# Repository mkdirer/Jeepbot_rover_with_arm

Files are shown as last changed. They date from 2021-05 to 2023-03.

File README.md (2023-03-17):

# Rover with arm
The Jeep-Bot project is an educational manipulator placed on a rover that uses stepper motors to drive its individual axes. The project can be divided into three parts: mechanical and electronic construction, software development, and application creation.

## Purpose and Scope
The main goal of the project is to create a cheap and functional design that can be controlled by a simple application. The project aims to achieve this goal by designing the mechanical parts of the Jeep-Bot, creating the robot's electronics to work with an external control system, writing software, creating an application for control, and conducting research.

## Technical Documentation
The technical documentation of the project describes the mechanical and electronic construction of the robot, as well as the software used to control the actuators and the application. The robot's control system only allows basic exercises related to identifying the geometric parameters of the manipulator.

<p align="center">
  
  
  
</p>

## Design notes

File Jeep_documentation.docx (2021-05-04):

[Wpisz nazwę firmy]

Jeep-Bot

ramię robota na łaziku

Łukasz Wajda

08.06.2018

[Wpisz tutaj streszczenie dokumentu. Streszczenie jest zazwyczaj krótkim podsumowaniem treści dokumentu. Wpisz tutaj streszczenie dokumentu. Streszczenie jest zazwyczaj krótkim podsumowaniem treści dokumentu.]

Rozdział 1

# Wstęp

Projekt „Jeep-Bot” jest to manipulator dydaktyczny umieszczony na łaziku. Do napędu jego poszczególnych osi zastosowano silniki krokowe. Projekt można podzielić na trzy części: konstrukcję mechaniczną i elektroniczną, oprogramowanie i aplikację. Konstrukcja mechaniczna i układ sterowania robota, pozwala jedynie na wykonywanie na nim podstawowych ćwiczeń związanych z identyfikacją parametrów geometrycznych manipulatora.

## 1.1 Cel i zakres pracy

Głównym celem stworzenia projektu jest wykonanie jak najtańszej, w miarę funkcjonalnej konstrukcji sterowanej prostą aplikacją. Stworzenie stanowiska z poruszającym się manipulatorem realizowane jest przez:

- wykonanie części mechanicznej Jeep-bota,
- zaprojektowanie i wykonanie elektroniki robota, pozwalającej współpracować z zewnętrznym układem sterowania,
- napisanie oprogramowania,
- stworzeni aplikacji do sterowania,
- przeprowadzenie badań.

W dokumentacji technicznej robota zamieszczono opis konstrukcji części mechanicznej i elektronicznej robota. Opisano też oprogramowanie służące do obsługi

układów wykonawczych wraz z aplikacją.

## 1.2 Czas przygotowania

Przygotowanie projektu trwało około 2 tygodni. Ten aktywnie spędzony czas można podzielić na kilka etapów. Pierwszy to pozyskanie niezbędnych części i złożenie projektu według własnego pomysłu. Drugi to pisanie jednocześnie programu pod Arduino UNO (mikrokontroler sterujący) i pod aplikację utworzoną w MIT App Inventor, wraz z testowaniem kilku linijek kodu. Trzeci etap to z kolei jego opisanie oraz przygotowanie niezbędnych schematów.

Rozdział 2

# Konstrukcja robota „Jeep-bot”

## 2.1 Konstrukcja mechaniczna

Projekt „Jeep-Bot” można podzielić na dwie podstawowe części: Ramię i Łazik. Rysunek ramienia powstał na podstawie projektu manipulatora MeArm Classic (https://shop.mime.co.uk/products/mearm-pocket-sized-robot-arm). Pozwoliłem sobie na kilka modyfikacji i udoskonaleń, ponieważ jego pierwowzór był przeznaczony na serwa modelarskie. Ja natomiast zaopatrzyłem się w tanie i dość wydajne silniki krokowe.

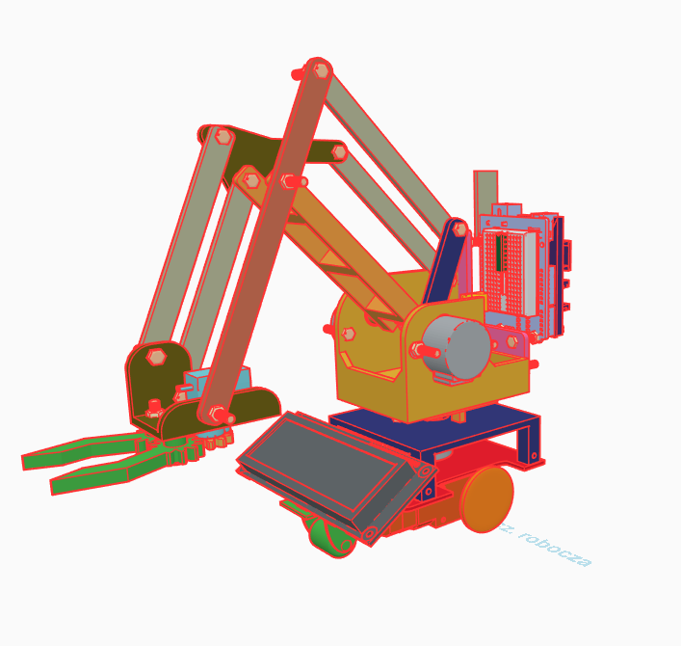
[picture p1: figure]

Do modyfikacji manipulatora posłużyłem się prostym i darmowym narzędziem online do tworzenia i edycji modeli 3D o nazwie TinkerCAD (jest własnością firmy Autodesk). Umieszczenie silników w skrzynce ma swoje pozytywne konsekwencje, a mianowicie stanowią on swego rodzaju przeciwwagę, co ma znaczenie ze względu na utrzymanie równowagi potrzebnej podczas ruchu głównego ramienia. Ramię zostało w całości wydrukowane na drukarce 3D. Jako materiał wybrałem ABS -tworzywo (https://pl.wikipedia.org/wiki/Tworzywa_sztuczne) otrzymywane w procesie polimeryzacji, które cechuje się dużą udarność (https://pl.wikipedia.org/wiki/Udarno%C5%9B%C4%87), twardością oraz odpornością na zarysowania. Jednak największym mankamentem tego materiału jest odklejanie się cienkich przedmiotów od stołu drukarki w czasie drukowania. Poniżej przedstawiono poszczególne kroki łączenia elementów.

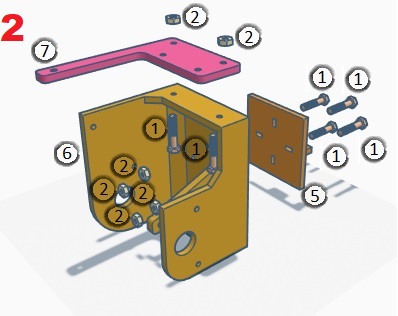
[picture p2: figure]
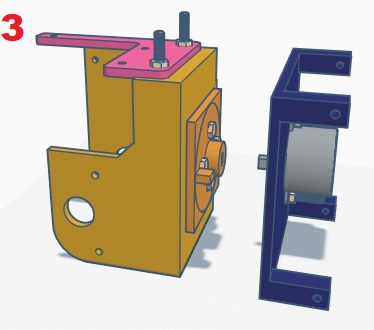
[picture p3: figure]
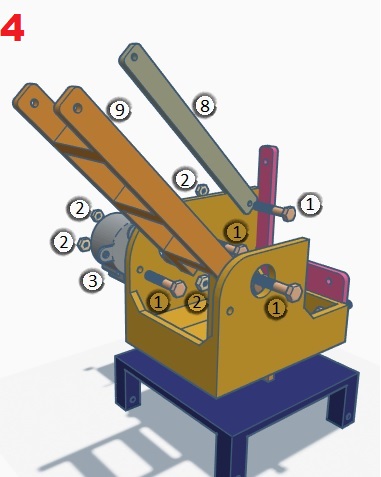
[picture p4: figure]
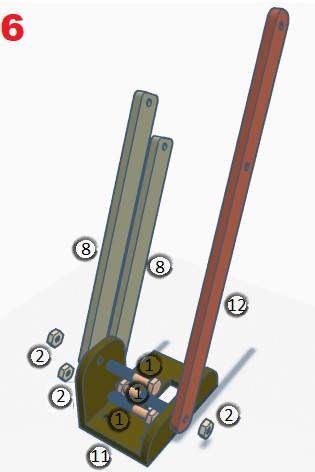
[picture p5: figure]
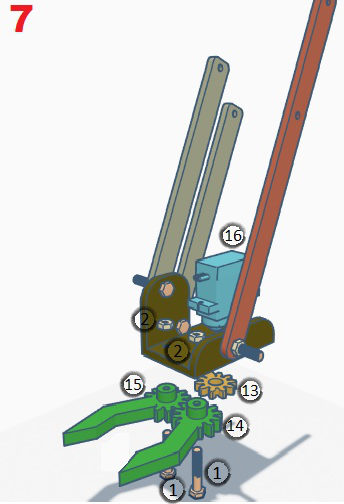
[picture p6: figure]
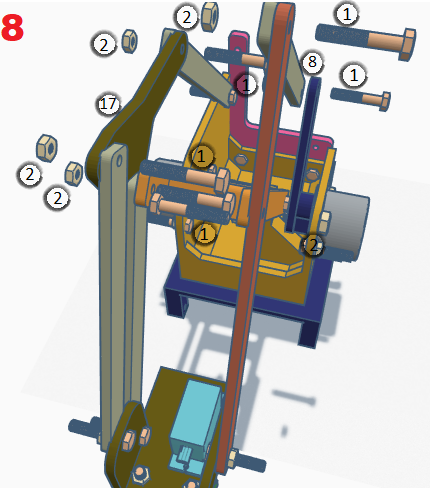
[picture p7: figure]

Płytki laminatu pod łazik zostały wycięta szlifierką i sklejone ciepłym klejem na których wspiera się manipulator. Poniżej zostało przedstawione umiejscowione dwóch silników i jednej rolki.

LISTA CZĘŚCI
Numer | Nazwa Części | Ilość
1 | M3 x 20mm Śruba | 29
2 | Nakrętka M3 | 32
3 | Silnik krokowy 28BYJ-48 | 3
4 | Podstawa manipulatora | 1
5 | Łącznik z silnikiem osi X | 1
6 | Skrzynia | 1
7 | Uchwyt na Arduino | 1
8 | Łącznik 100mm | 4
9 | Ramię silnika osi Z | 1
10 | Ramię silnika osi Y | 1
11 | Podstawa chwytaka | 1
12 | Łącznik 160mm | 1
13 | Koło zębate serwa | 1
14 | Chwytak lewy | 1
15 | Chwytak prawy | 1
16 | Micro Serwo 9g Tower Pro | 1
17 | Prawy górny łącznik | 1
18 | Płytka laminatu | 1
19 | Silnik DC z redukcją | 2
20 | Płytka obrotowa z kółkiem 22mm | 1
21 | Arduino Uno | 1
22 | CNC Shield | 1
23 | Sterownik A4988 (http://botland.com.pl/sterowniki-silnikow-krokowych/148-sterownik-silnika-krokowego-a4988-reprap-35v-2a-modul-pololu.html) | 3
24 | Płytka stykowa | 1
25 | Stabilizator LM7805 | 1
26 | Mostek H L293d | 1
27 | Moduł HC-06 | 1
28 | Wyświetlacz LCD 2x16 z konwerterem I2C HD 44780 | 1

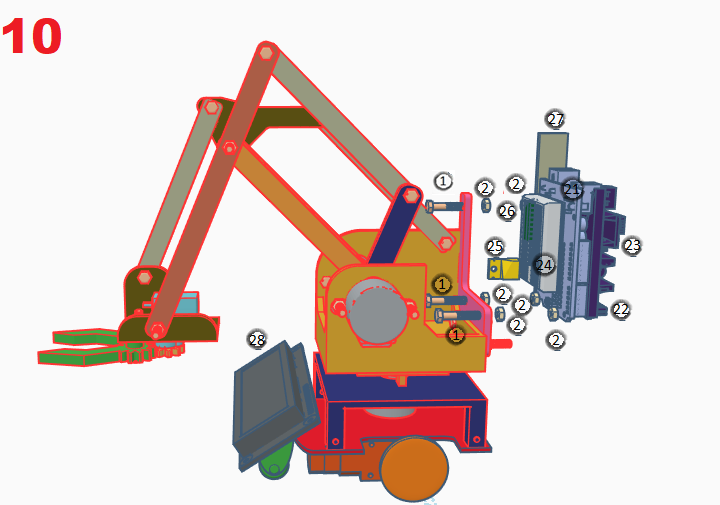
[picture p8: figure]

Pliki do druku zostały umieszczone w załączniku.

## 2.2 Konstrukcja elektroniczna

Sercem odpowiedzialnym za dokonywanie obliczeń, odbieranie danych i ich wysyłanie jest Arduino UNO, którego opis wyprowadzeń dla CNC shield i przykładowe umieszczenie przedstawiono poniżej.

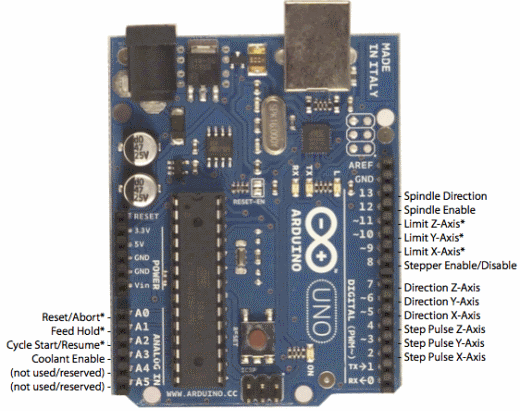
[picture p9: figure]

Specjalna nakładka CNC shield pozwala na wygodne umiejscowienie czterech sterowników silników A4988 (http://botland.com.pl/sterowniki-silnikow-krokowych/148-sterownik-silnika-krokowego-a4988-reprap-35v-2a-modul-pololu.html). W znaczący sposób ułatwia to korzystanie z silników krokowych odpowiedzialnych za poruszanie ramieniem w różnych płaszczyznach x, y i z .

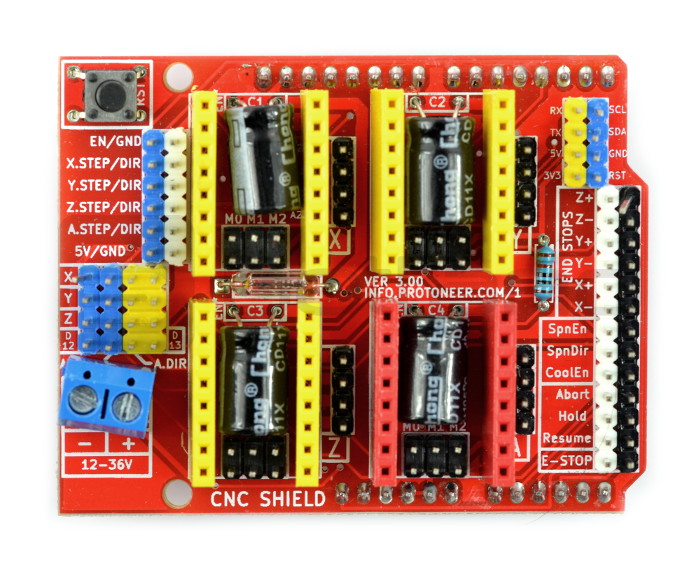
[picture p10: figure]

Silniki krokowe 28BYJ-48 są silnikami unipolarnymi, natomiast płytka jak i sterowniki są przeznaczone na silniki bipolarne. Ich przemiana była bardzo prosta i obejmowała ściągnięcie obudowy i zarysowanie, usunięcie jednej ścieżki łączącej środki uzwojeń silników.

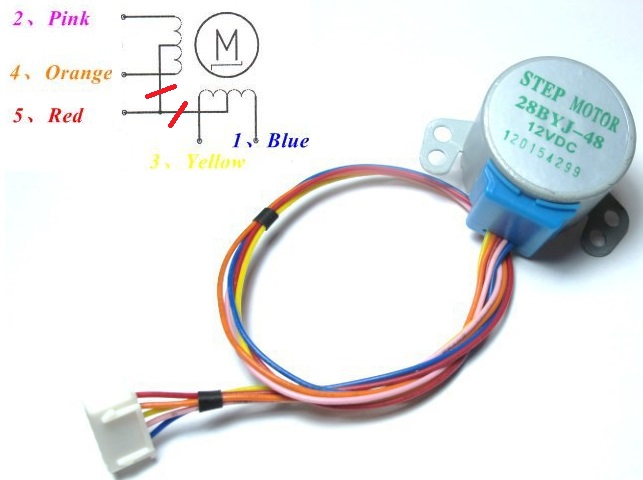
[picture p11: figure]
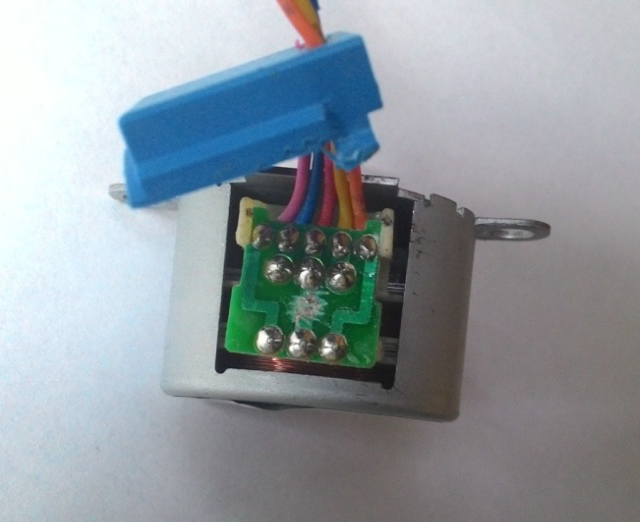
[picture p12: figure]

Do sterowania silnikami krokowymi za pomocą A4988 (http://botland.com.pl/sterowniki-silnikow-krokowych/148-sterownik-silnika-krokowego-a4988-reprap-35v-2a-modul-pololu.html) wymagane są dwa piny sterujące STEP i DIR. Jeden impuls podany na pin STEP powoduje jeden krok silnika w kierunku wybranym poprzez podanie odpowiedniego stanu logicznego na pin DIR.

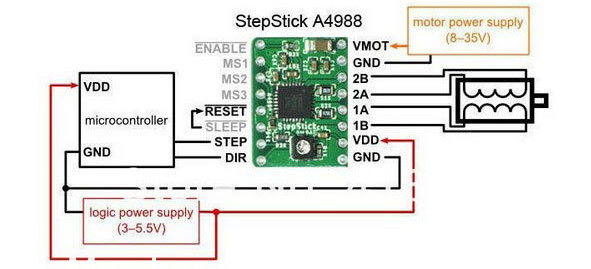
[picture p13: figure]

Mechanizmem który porusza chwytakiem w ramieniu jest serwo, wymaga tylko jednego pinu sterującego. Wyświetlacz LCD 2x16 został połączony z konwerterem I2C HD 44780. Dzięki temu połączenie między Arduino UNO, a wyświetlaczem zajmuje 4 piny (SCL, SDA, Vcc i GND).

Silniki DC łazika są odpowiednio połączone z L293d, mostkiem H (zgodnie z poniższym schematem). Całość jest zasilana napięciem 9V i 5V po stabilizatorze LM7805.

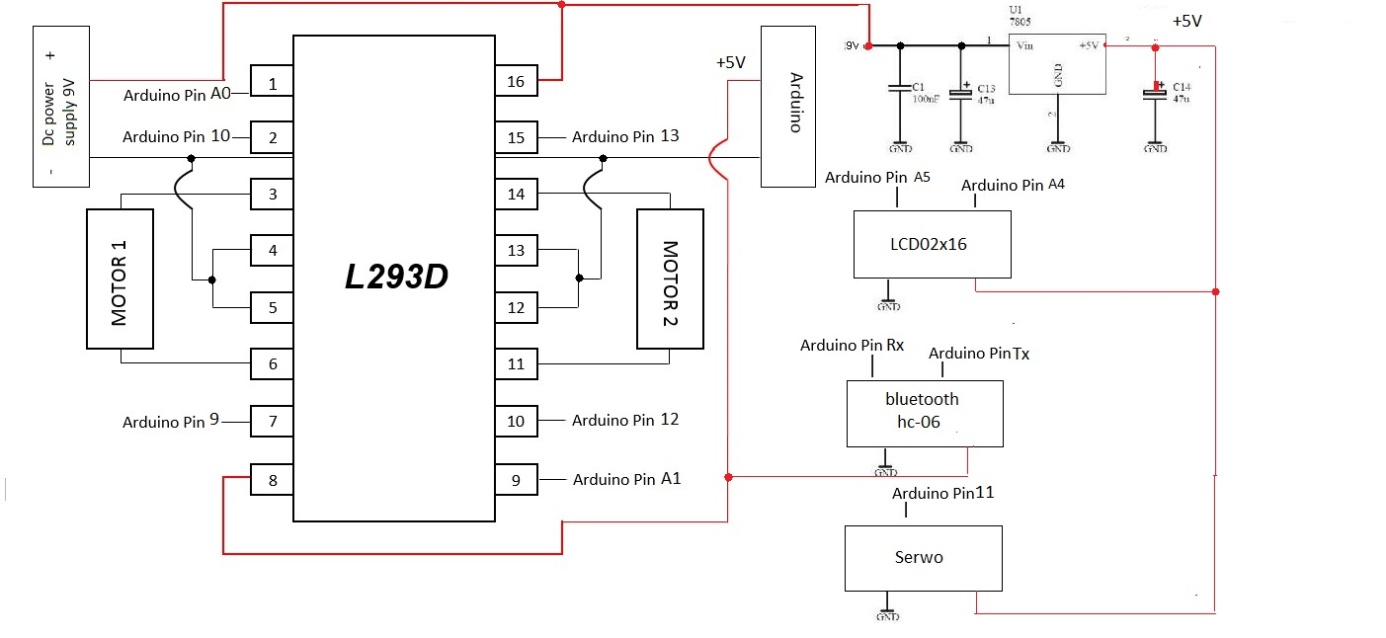
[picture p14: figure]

Najważniejszym elementem zapewniającym komunikację z aplikacją jest moduł Bluetooth HC-06. Na koniec wszystko powinno wyglądać tak

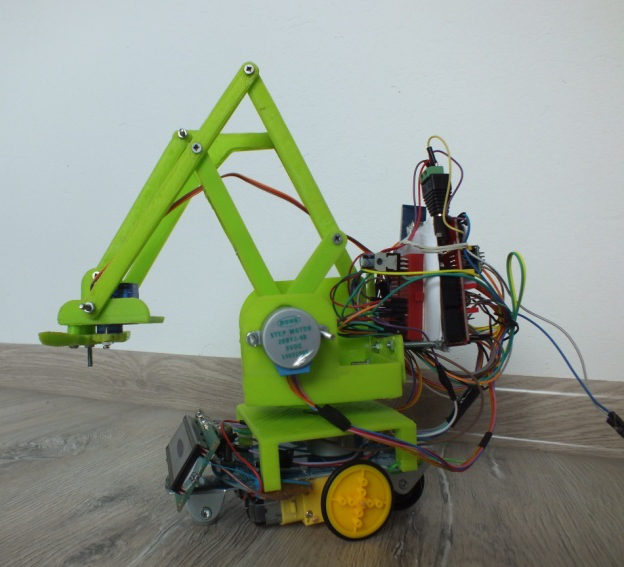
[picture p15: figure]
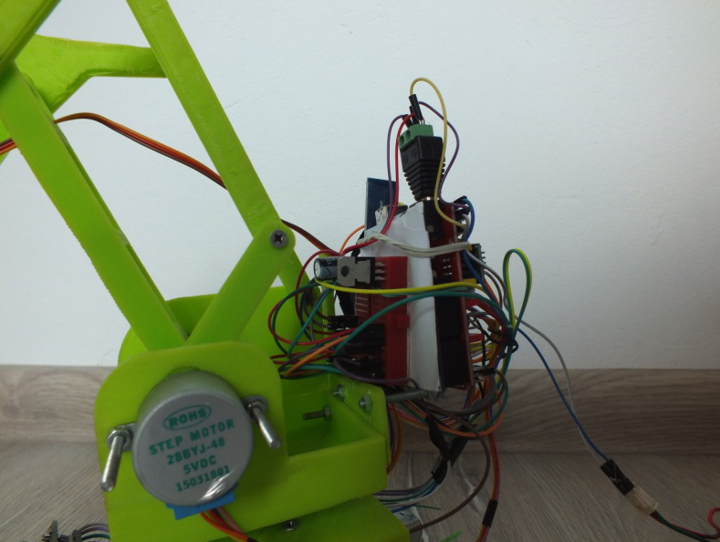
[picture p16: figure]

## 2.3 Aplikacja

Do stworzenia aplikacji użyłem programu wizualnego MIT App Inventor. App Inventor umożliwia tworzenie aplikacji dla telefonów z systemem Android za pomocą przeglądarki internetowej i podłączonego telefonu lub emulatora. Budujemy aplikacje poprzez współpracę z:

- App Inventor Designer, gdzie można wybrać składniki.

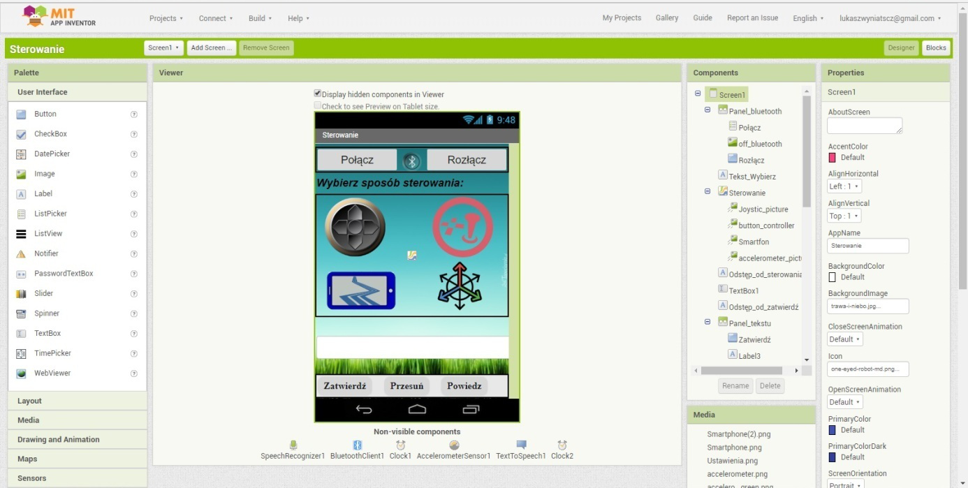
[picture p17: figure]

- App Inventor Blocks Editor, gdzie można zbudować bloki programu, które określają, w jaki sposób elementy powinny się zachowywać.

Każdemu składnikowi na ekranie tworzonej aplikacji odpowiadają konkretne bloki. Na samym początku okno startowe aplikacji wymaga od nas połączenia za pomocą Bluetooth. Wówczas aktywny jest tylko przycisk Połącz, dzięki procedurze przyciski_startu_po_rozłączeniu. Do inicjalizacji ekranu wchodzą również komendy takie jak : akcelerometr jest wyłączony i ustawiany joysticka w odpowiedniej pozycji, które szerzej zostaną opisane później.

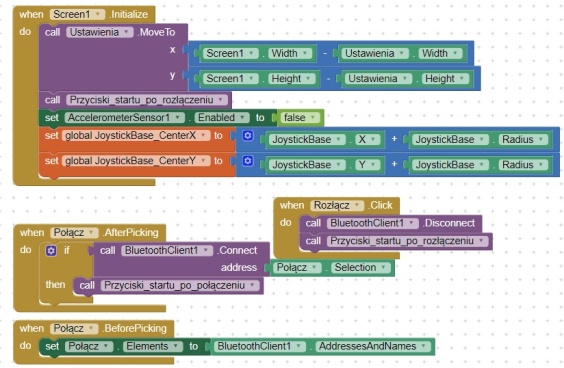
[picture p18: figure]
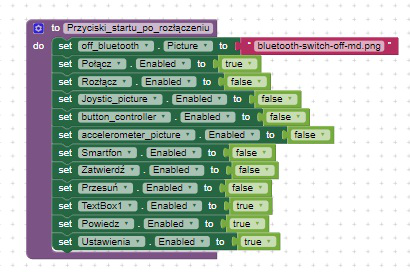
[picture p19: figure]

Po wybraniu znanego nam połączenia bluetooth mamy do wyboru kilka metod sterowania łazikiem, jak np.: przyciski, joystick, akcelerometr oraz przykładowy ruch i jedną metodę sterowania ramieniem.

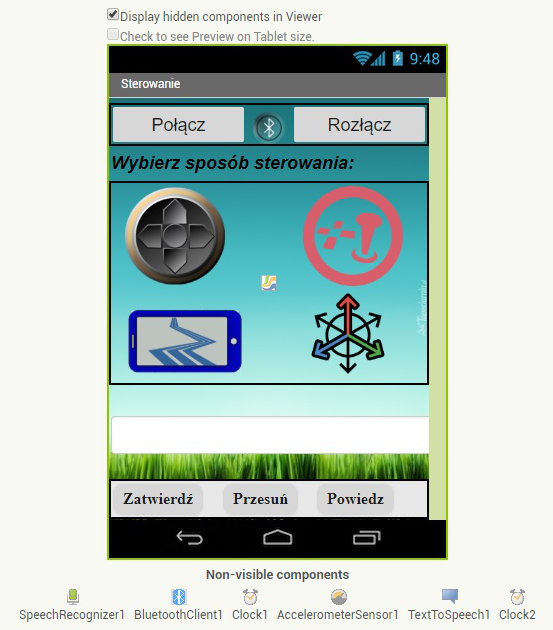
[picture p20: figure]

Dodatkowo możemy wysłać przykładowy tekst na wyświetlacz LCD, przesunąć go i sprawić, że nasz smartfon wypowie napisane słowo.

Po wybraniu dowolnego sposobu sterowania np. za pomocą przycisków, wykonywane są odpowiednie procedury odpowiedzialne za zakrywanie bądź odsłanianie konkretnych komponentów, tak aby uzyskać żądany ekran. Poniżej przedstawiono używane procedury.

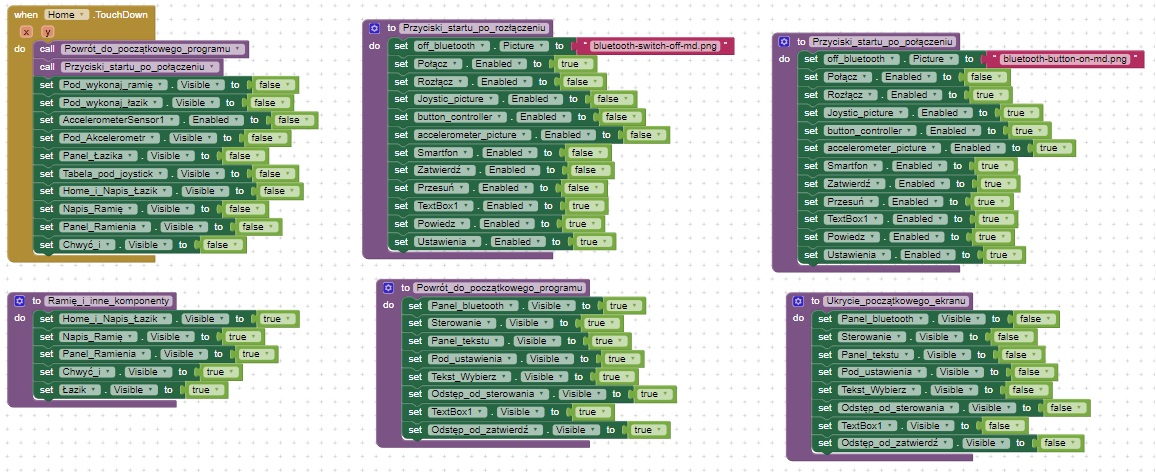
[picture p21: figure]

Co nastąpi kiedy naciśniemy wybrany przycisk.

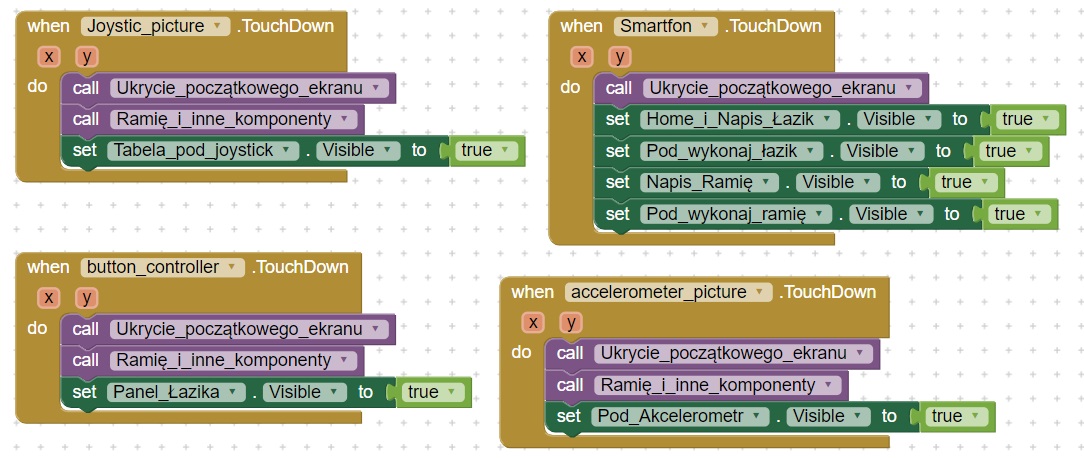
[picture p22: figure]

Uzyskane ekrany pod sterowanie:

- Przyciskami,
- Joystick,
- Akcelerometr,
- Przykładowy ruch.

W przypadku joysticka i akcelerometru musiałem utworzyć martwe pole, w którym nie jest wysyłana żadna komenda do łazika. Z przedstawionych bloków można się domyślić, że dla joysticka pole to jest kwadratem o boku 80 pikseli i po jego przekroczeniu wysyłana jest odpowiednia widomość. Ogólnie czerwony joystick może się poruszać po polu czarnego koła o średnicy 160 pikseli. Kiedy joystick jest nieużywany wraca do położenia środkowego martwego pola.

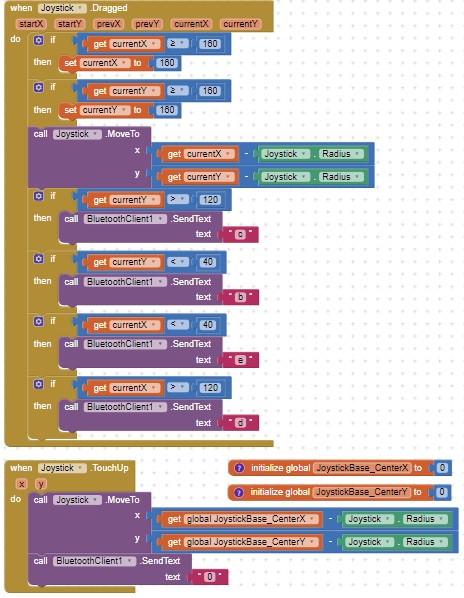
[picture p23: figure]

Dla akcelerometru sprawa ma się podobnie. W tym przypadku działamy tylko w dwóch płaszczyznach, osi X i Z. Do każdej osi jest przyporządkowany odpowiedni przedział, w którym jest wysyłana komenda „0” odpowiedzialna za bezruch. Dopiero jej przekroczenie skutkuje ruchem łazika.

Aplikacja jest tak zaprojektowana, aby w czasie naciśnięcia przycisku, bądź zadziałaniu akcelerometru lub joystick smartfon wysyłał poszczególne znaki np.: ‘1’, ‘2’, ‘A’, ’B’, ‘C’ itp.

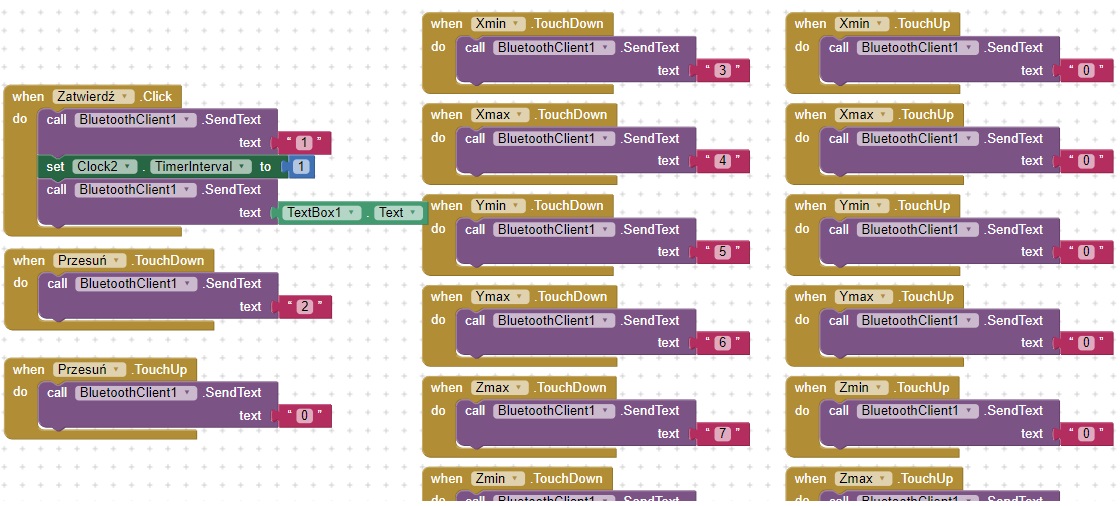
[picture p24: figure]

Kolejno moduł Bluetooth odbiera ciąg znaków, które za pomocą programu są przekształcane na poszczególne czynności. Program z opisem pod mikrokontroler wraz z aplikacją w załączniku.

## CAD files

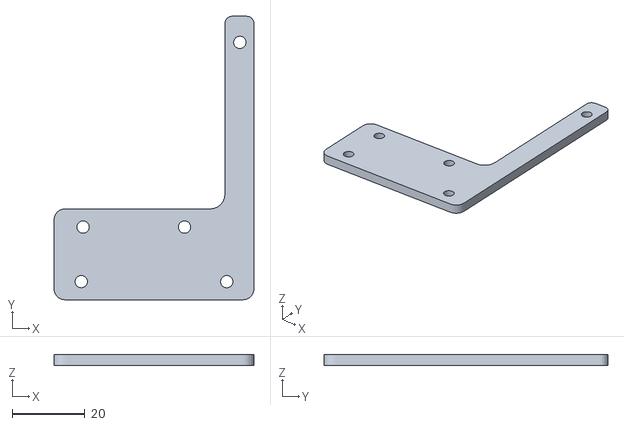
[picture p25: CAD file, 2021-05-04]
Part_to_3D_print/_uchwyt na Arduino.stl
55.0 x 78.0 x 3.00

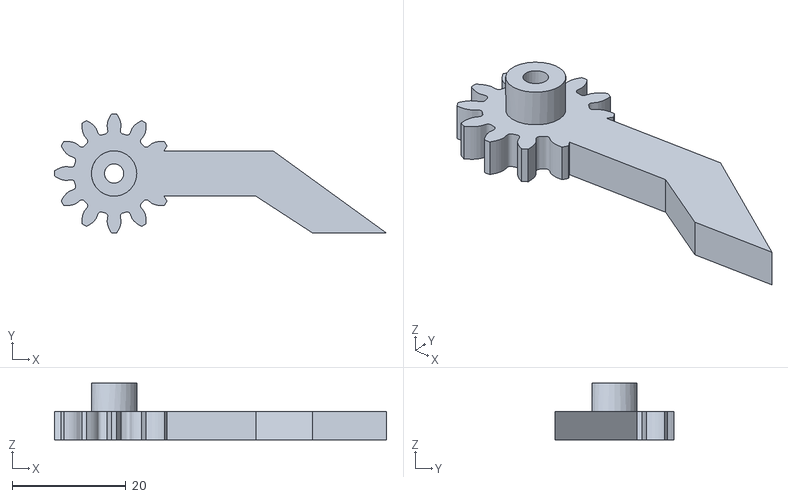
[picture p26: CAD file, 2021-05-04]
Part_to_3D_print/_chwytak lewy.stl
58.5 x 21.0 x 10.0

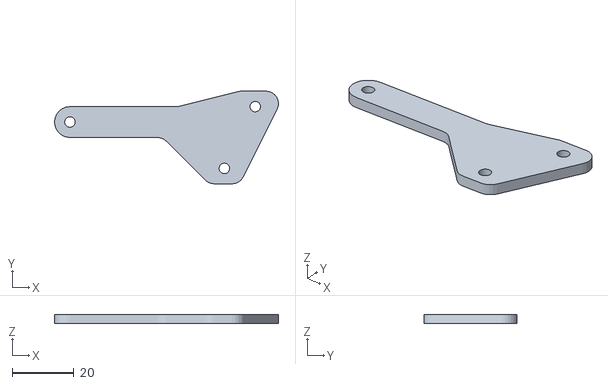
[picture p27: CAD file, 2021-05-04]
Part_to_3D_print/_prawy gorny łacznik.stl
72.5 x 30.0 x 3.00

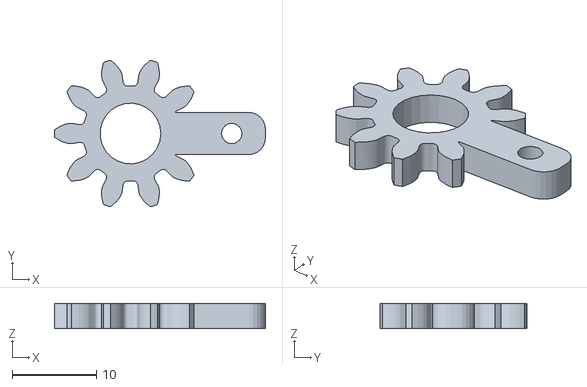
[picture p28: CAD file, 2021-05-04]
Part_to_3D_print/_koło zebate serwa.stl
25.0 x 17.4 x 3.00

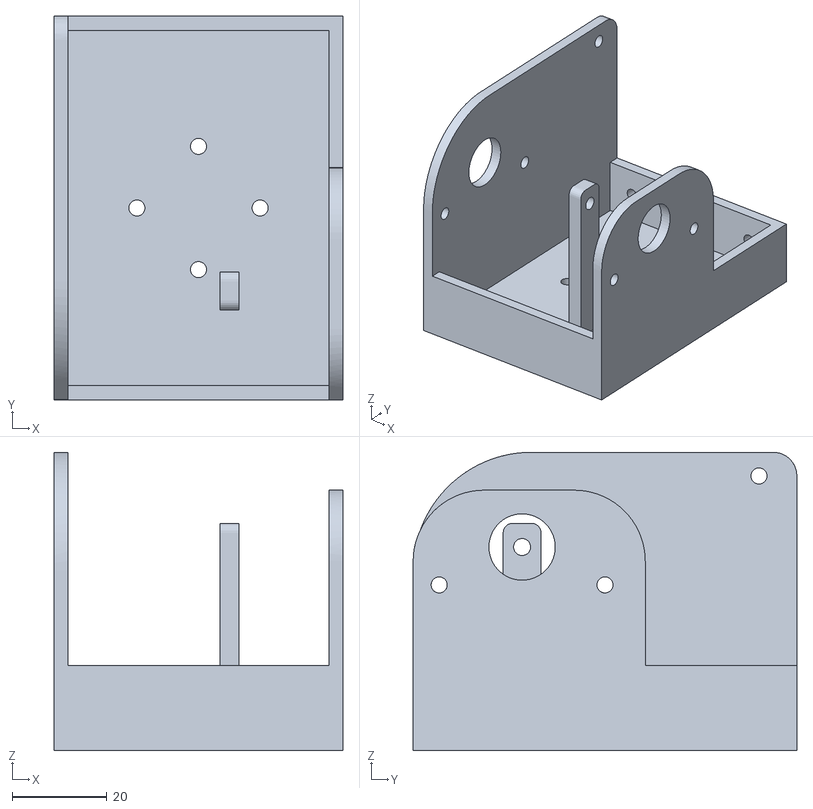
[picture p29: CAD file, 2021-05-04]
Part_to_3D_print/_skrzynia.stl
61.0 x 81.0 x 63.0

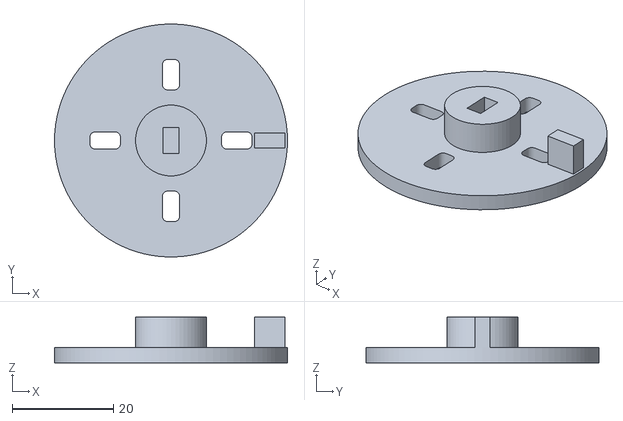
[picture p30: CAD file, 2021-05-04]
Part_to_3D_print/_łacznik z silnikiem osi X.stl
46.0 x 46.0 x 9.00

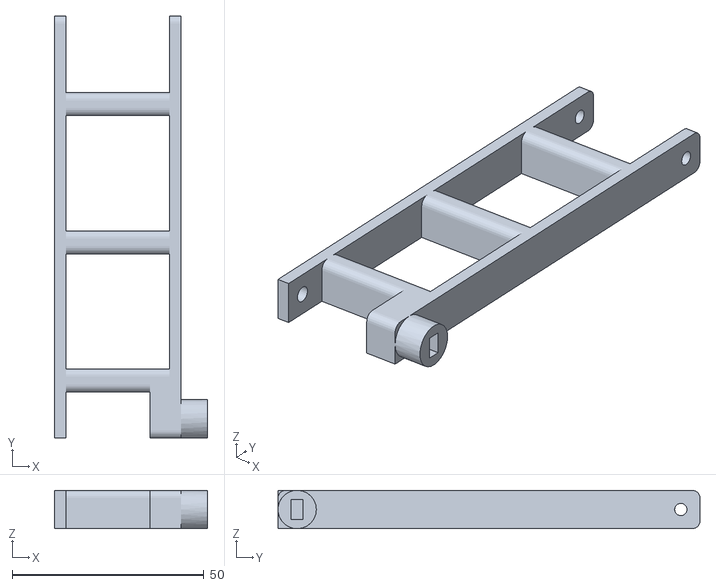
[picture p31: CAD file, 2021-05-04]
Part_to_3D_print/_ramie silnika osi Z.stl
40.0 x 110.0 x 10.0

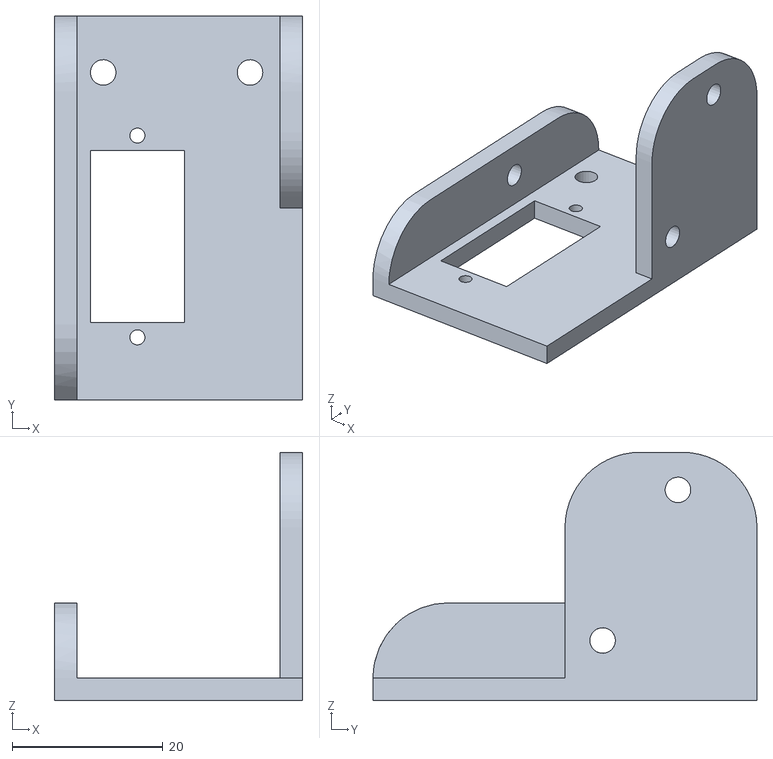
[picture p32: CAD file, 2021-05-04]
Part_to_3D_print/_podstawa chwytaka.stl
33.0 x 51.0 x 33.0

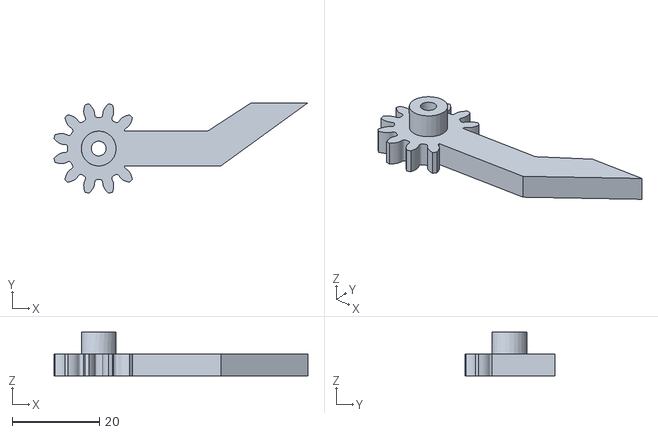
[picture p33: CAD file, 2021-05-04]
Part_to_3D_print/_chwytak prawy.stl
58.3 x 20.8 x 10.0

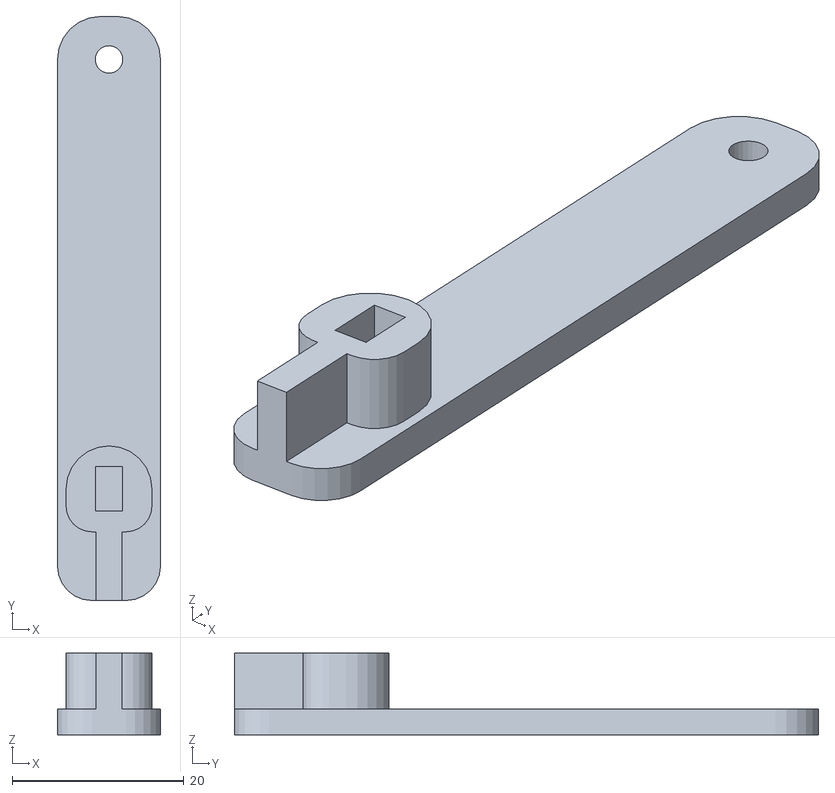
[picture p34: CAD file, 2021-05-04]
Part_to_3D_print/_ramie silnika osi Y.stl
12.0 x 68.0 x 9.50

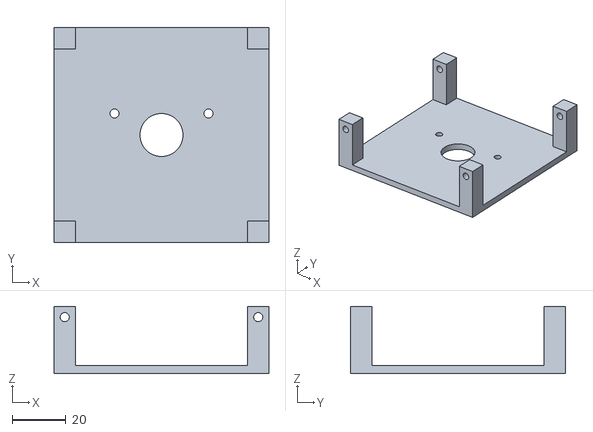
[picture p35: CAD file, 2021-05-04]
Part_to_3D_print/_podstawa manipulatora.stl
80.0 x 80.0 x 25.0

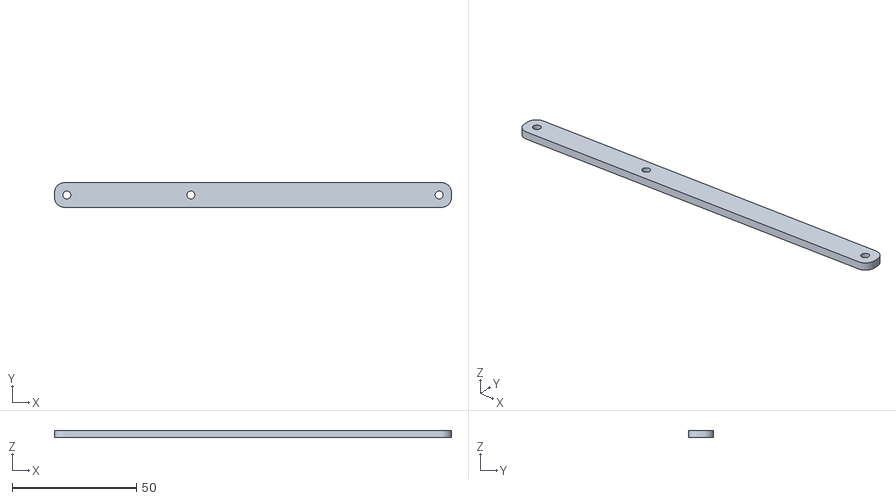
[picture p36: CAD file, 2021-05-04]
Part_to_3D_print/_łacznik 160mm.stl
160.0 x 10.0 x 3.00

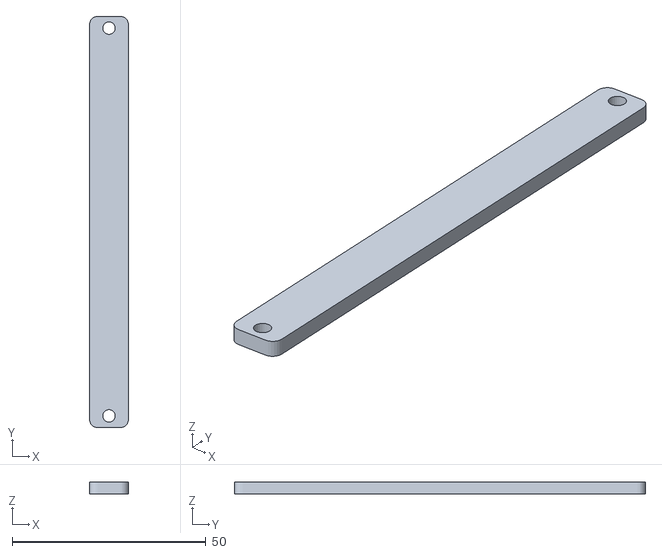
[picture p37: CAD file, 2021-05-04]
Part_to_3D_print/_łacznik 100mm.stl
10.0 x 106.0 x 3.00

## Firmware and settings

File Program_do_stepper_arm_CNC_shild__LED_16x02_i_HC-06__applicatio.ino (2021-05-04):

// Poniżej przedstawiono proste procedury sterowania silnikiem krokowym
# define EN 8 // Aktywacja silników krokowych, aktywny stan niski
# define X_DIR 5 // Sterowanie kierunkiem silnika krokowego w osi X.
# define Y_DIR 6 // Sterowanie kierunkiem silnika krokowego w osi Y.
# define Z_DIR 7 // Sterowanie kierunkiem silnika krokowego w osi Z.
# define X_STP 2 // Sterowanie krokowe, impulsowe x-osi
# define Y_STP 3 // Sterowanie krokowe, impulsowe y-osi
# define Z_STP 4 // Sterowanie krokowe, impulsowe x-osi

#include <Servo.h> //Biblioteka odpowiedzialna za serwa
#define serw 11 // Nazwanie pinu pod kontrolowanie serwa
Servo serwomechanizm;  //Tworzymy obiekt, dzięki któremu możemy odwołać się do serwa

char state;// Utworzenie zmiennej do odczytywania przesyłanych znaków

String message; // ciąg, który przechowuje wiadomość przychodzącą
#include <Wire.h> //
#include <LiquidCrystal_I2C.h> // biblioteki niezbędne do obsługi LCD
LiquidCrystal_I2C lcd(0x27, 16, 2);//Informacja o podłączeniu nowego wyświetlacza

#define pwmMotorA A0 // Sterowanie PWM silnikiem DC A (odpowiada z prędkość obrotów silnik A)
#define pwmMotorB A1 // Sterowanie PWM silnikiem DC B (odpowiada z prędkość obrotów silnik B)
#define ForwardA 9
#define BackA 10
#define ForwardB 12
#define BackB 13

// Funkcja: step. funkcja: do sterowania kierunkiem silnika krokowego, liczba kroków.
//Parametry: dir-sterowanie kierunkiem jazdy, dirPin-pin pod kierunek jazdy, 
//steps-liczba kroków, stepperPin- pin pod liczbę kroków

void step (boolean dir, byte dirPin, byte stepperPin, int steps)
{ digitalWrite (EN, LOW);
    digitalWrite (dirPin, dir);
    delay (30);
    for (int i = 0; i <steps; i++) 
    {
        digitalWrite (stepperPin, HIGH);
        delayMicroseconds (700);
        digitalWrite (stepperPin, LOW);
        delayMicroseconds (700);
    }
}
void ster (boolean dir, byte dirPin, byte stepperPin)
{for (int i = 0; i <15; i++)
  {digitalWrite (EN, LOW);
  digitalWrite (dirPin, dir);
    digitalWrite (stepperPin, HIGH);
        delayMicroseconds (700);
        digitalWrite (stepperPin, LOW);
        delayMicroseconds (700);}
    
}
//funkcja skręt w lewo
void Left(){
  //Ustawienie kierunku obrotów A
  digitalWrite(ForwardA, LOW); 
  digitalWrite(BackA, HIGH);
  //Ustawienie kierunku obrotów B
  digitalWrite(ForwardB, HIGH); 
  digitalWrite(BackB, LOW);
  //delay(1000);
}

//skręt w prawo
void Right(){
  //Ustawienie kierunku obrotów A
  digitalWrite(ForwardA, HIGH); 
  digitalWrite(BackA, LOW);
  //Ustawienie kierunku obrotów B
  digitalWrite(ForwardB, LOW); 
  digitalWrite(BackB, HIGH);
  
  //delay(1000);
}

//jazda prosto
void Forward(){
  //Ustawienie kierunku obrotów A
  digitalWrite(ForwardA, HIGH); 
  digitalWrite(BackA, LOW);
  
  //Ustawienie kierunku obrotów B
  digitalWrite(ForwardB, HIGH); 
  digitalWrite(BackB, LOW);
}

//cofanie
void Back(){
  //Ustawienie kierunku obrotów A
  digitalWrite(ForwardA, LOW); 
  digitalWrite(BackA, HIGH);
  
  //Ustawienie kierunku obrotów B
  digitalWrite(ForwardB, LOW); 
  digitalWrite(BackB, HIGH);
  
}
//zatrzymanie
void Stop(){
  //Ustawienie kierunku obrotów A
  digitalWrite(ForwardA, LOW); 
  digitalWrite(BackA, LOW);
  
  //Ustawienie kierunku obrotów B
  digitalWrite(ForwardB, LOW); 
  digitalWrite(BackB, LOW);
}

void setup () {   // Ustawienie pinów jako wyjścia
    pinMode (X_DIR, OUTPUT); pinMode (X_STP, OUTPUT);
    pinMode (Y_DIR, OUTPUT); pinMode (Y_STP, OUTPUT);
    pinMode (Z_DIR, OUTPUT); pinMode (Z_STP, OUTPUT);
    pinMode (EN, OUTPUT);
    serwomechanizm.attach(serw); //Serwomechanizm podłączony do pinu 11
    digitalWrite (EN, HIGH);
    Serial.begin(9600); //Uruchamiamy transmisję
    lcd.begin();//Deklaracja typu  
    lcd.print("Witaj");// Komenda powitalna
    
     //Wyjście PWM kanału A
  pinMode(pwmMotorA, OUTPUT); 
  
  //Wyjście cyfrowe AIN1
  pinMode(ForwardA, OUTPUT); 
  //Wyjście cyfrowe AIN2
  pinMode(BackA, OUTPUT);   
  
  //Wyjście PWM kanału B
  pinMode(pwmMotorA, OUTPUT);
  
  //Wyjście cyfrowe BIN1
  pinMode(ForwardB, OUTPUT); 
  //Wyjście cyfrowe BIN2
  pinMode(BackB, OUTPUT); 
  
  
  //ustawienie prędkości obrotowej silników
 digitalWrite(pwmMotorA, HIGH);//ustawienie maksymalnej prędkości
 digitalWrite(pwmMotorB, HIGH);
   
}

void loop () {
    if(Serial.available() > 0){ //Czy Arduino odebrało dane    
      state = Serial.read();}//Jeśli tak, to odczytaj je i zapisz w zmiennej state
    //lub while
    switch(state){
    case '0':
    Stop();
    break;
    case '1':
    lcd.clear();// czyszczenie ekranu LCD
     while(Serial.available()){     
       message+=char(Serial.read());// przechowuj ciąg od polecenia szeregowego
     }
      if(message!="")// jeśli dane istnieją
    {lcd.print(message);// pojawienie się wysłanej wiadomości na ekranie LCD
      delay(1100);//
      message=""; //czyszczenie danych
    }
    state='0';
    break;
     case '2':
     for (int positionCounter = 0; positionCounter < 16; positionCounter++) {
    // przewiń o jedną pozycję w lewo:
    lcd.scrollDisplayLeft();
    // czekaj chwilę:
    delay(200);
  } 
    break;
    case '3':
    ster (false, X_DIR, X_STP); // Obrót osi silnika X w tył
    case '4':
    ster (true, X_DIR, X_STP); // Obrót osi silnika X w przód
    break;
     case '5':
       ster (false, Y_DIR, Y_STP); 
    break;
    case '6':
    ster (true, Y_DIR, Y_STP); 
    break;
     case '7':
       ster (false, Z_DIR, Z_STP); 
    break;
    case '8':
    ster (true, Z_DIR, Z_STP); // X axis motor reverse 1 ring, the 200 step is a circle.
    break;
     case '9':
    serwomechanizm.write(60);//Szczęki otwarte
    break;
    case 'a':
    serwomechanizm.write(0);//Sczęki zamknięte
    break;
    case'b':
    Forward();
    break;
    case 'c':
    Back();
    break;
    case'd':
    Right();
    break;
    case 'e':
    Left();
    break;
    case 'f':
    Forward();
    delay(350);
    Right();
    delay(300);
    Left();
    delay(300);
    Back();
    delay(350);
    break;
    case 'g':
    step (false, X_DIR, X_STP, 50); //Obrót osi silnika X w tył o 50 kroków
    step (false, Y_DIR, Y_STP, 50); 
    step (false, Z_DIR, Z_STP, 50); 
    serwomechanizm.write(0);//Sczęki zamknięte
    step (true, X_DIR, X_STP, 50); //Obrót osi silnika X w przód o 50 kroków
    step (true, Y_DIR, Y_STP, 50); 
    step (true, Z_DIR, Z_STP, 50); 
    serwomechanizm.write(60);//Szczęki otwarte
    state='0';
    break;
    default :
    Stop();
    break;
    }
    
     delay(35);   
   
     digitalWrite (EN, HIGH);// silniki krokowe wyłączone
   
}
